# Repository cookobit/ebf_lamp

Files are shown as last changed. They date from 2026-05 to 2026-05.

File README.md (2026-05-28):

# EBF Lamp Project

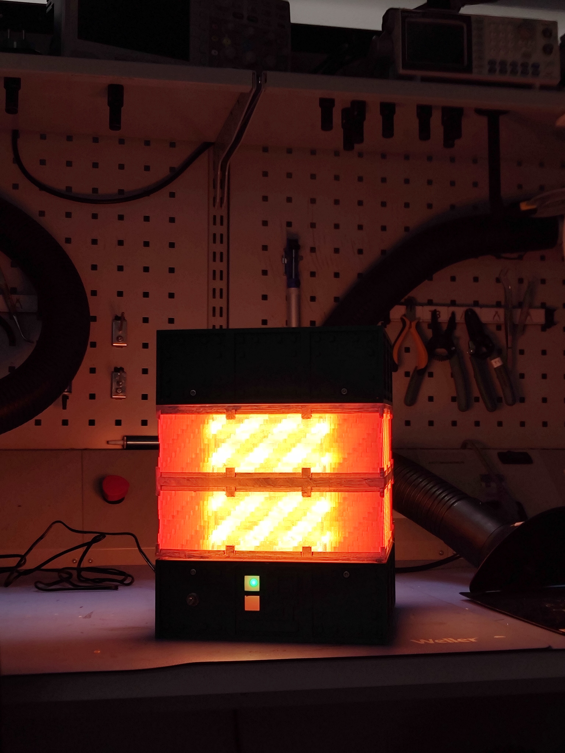
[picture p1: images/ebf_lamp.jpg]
EBF Lamp assembled


You came after the Electrical Blast Furnace (EBF) from GregTech modpacks, especially GTNH. 
This repository contains all production files to date, plus special 3D-print files you can print at home and assemble yourself.

## HOW TO PRINT THE EBF

1. Download the whole repository.
2. In the '3D_prints' folder, find files for 3D printing.
3. The STLs come in two options: the **lamp version**, or for the r**egular version** (empty inside), which is simpler.
4. The lamp version requires a custom PCB, a step-down voltage module, and a power inlet. Because of these custom components, a full reproduction of the lamp from this repo is not possible in its current state.

IMPORTANT: Current dimensions are 192x192x256 mm for the lamp, change the scale for regular version, since the lamp has mounting holes for M3 screws and other components.

## What's in this repository?
In short, the STLs I made so far, as well as some of the design files and software for ESP32 XIAO module. They are separated in two dedicated folders: firmware and hardware.
The firmware was used in the Arduino IDE for flashing the program there, and the hardware was designed in the KiCad, dedicated open-source PCB design software. 

## Plans for the future:

The repo won't have a complete support and maintained actively, because of the real life stuff.
* New PCB for electronics integration. It should integrate the power inlet and complete sensor and hardware integration.
* An optional buzzer for the EBF to make the "working" sounds.
* A humidifier on top, active while the EBF is "running".

## License
Hardware files are licensed under **CERN-OHL-P**; software is licensed under the **MIT License**. See the respective directories for full license text.

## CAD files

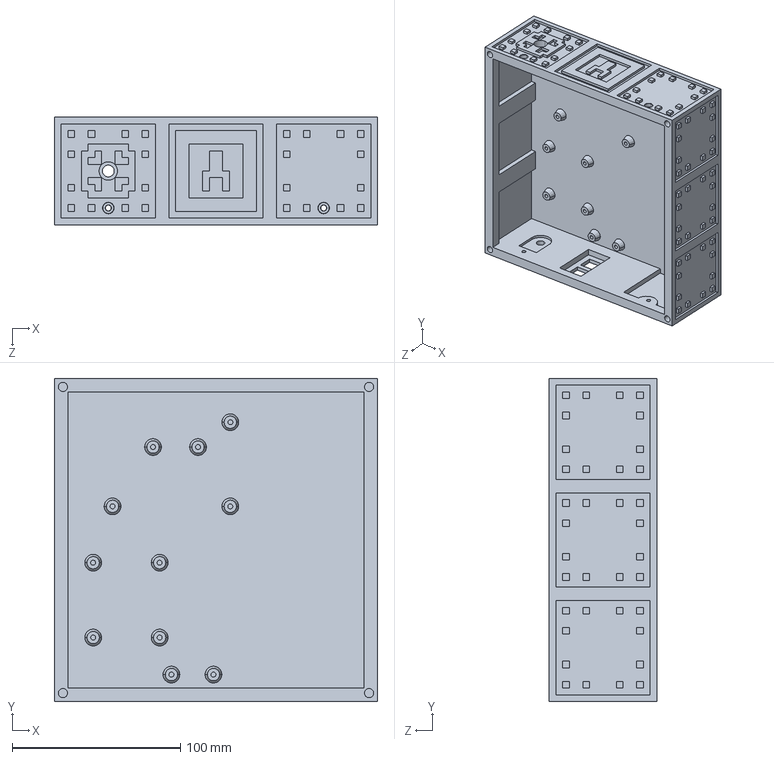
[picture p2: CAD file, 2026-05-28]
3D_prints/lamp_version/EBF_bottom.STEP
192.0 x 192.0 x 64.0 mm

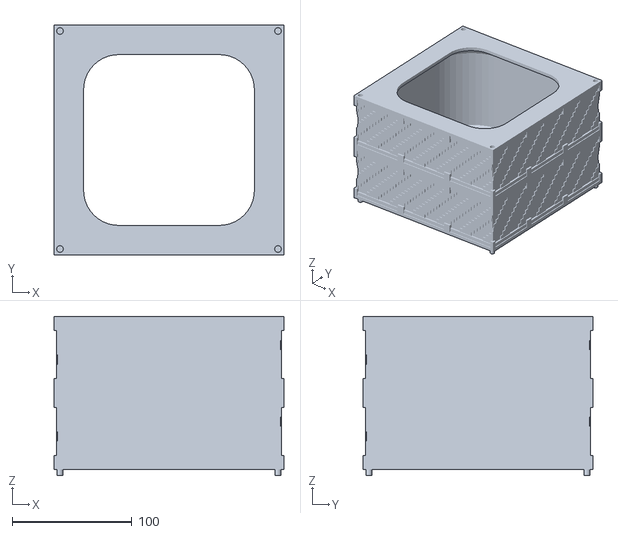
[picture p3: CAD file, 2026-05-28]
3D_prints/regular_version/EBF_coils_regular.STL
192.0 x 192.0 x 133.0

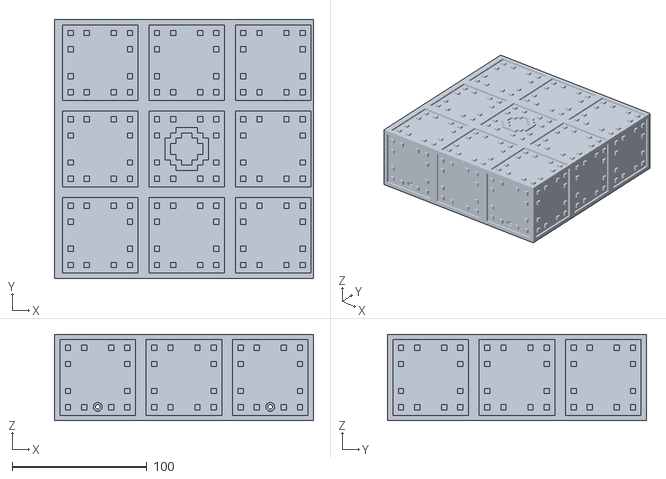
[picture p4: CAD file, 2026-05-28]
3D_prints/lamp_version/EBF_top.STL
192.0 x 192.0 x 64.0

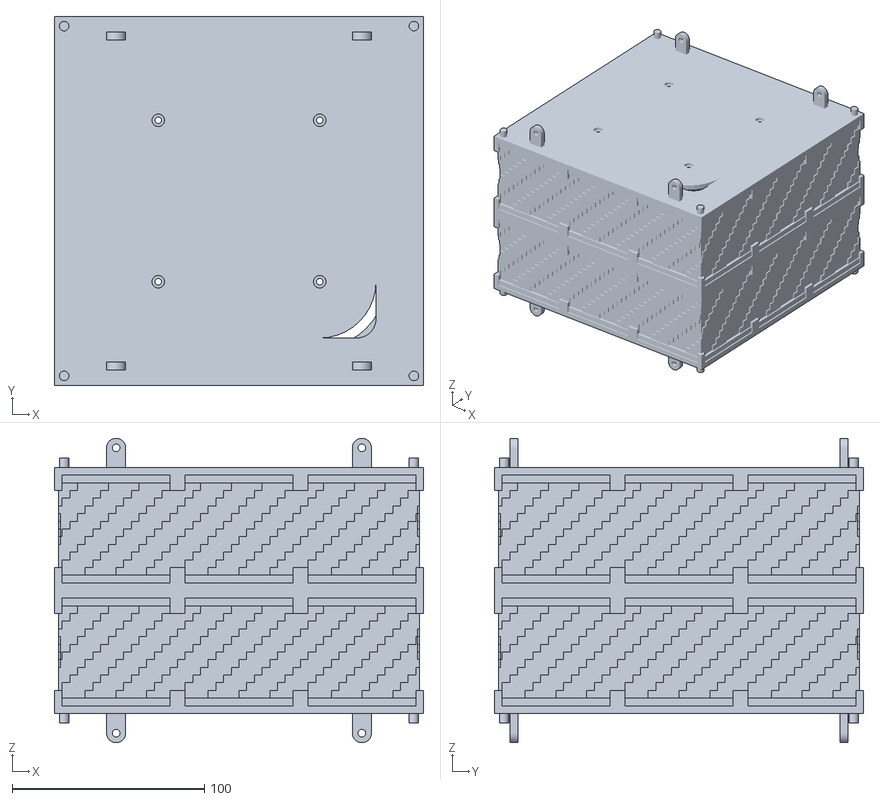
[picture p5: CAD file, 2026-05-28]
3D_prints/lamp_version/EBF_coils.STL
192.0 x 192.0 x 158.4

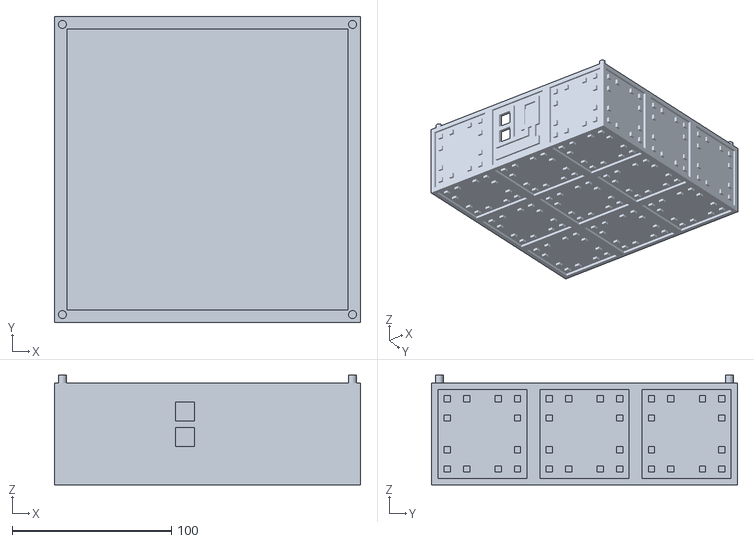
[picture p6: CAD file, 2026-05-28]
3D_prints/regular_version/EBF_bottom_regular.STL
192.0 x 192.0 x 69.0

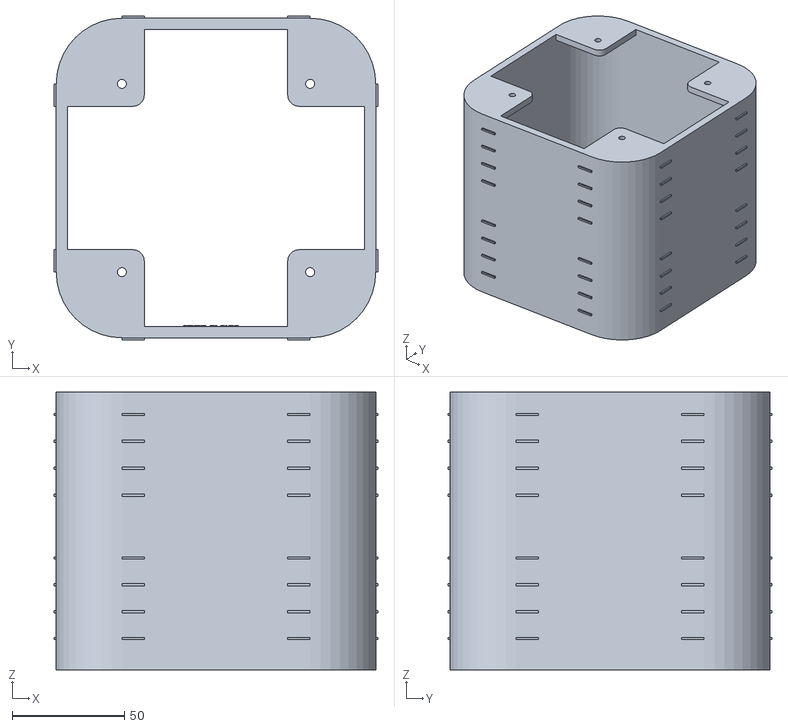
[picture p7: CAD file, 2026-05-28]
3D_prints/lamp_version/LED_holder.STL
144.6 x 144.6 x 124.0

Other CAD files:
3D_prints/regular_version/EBF_top_regular.STL

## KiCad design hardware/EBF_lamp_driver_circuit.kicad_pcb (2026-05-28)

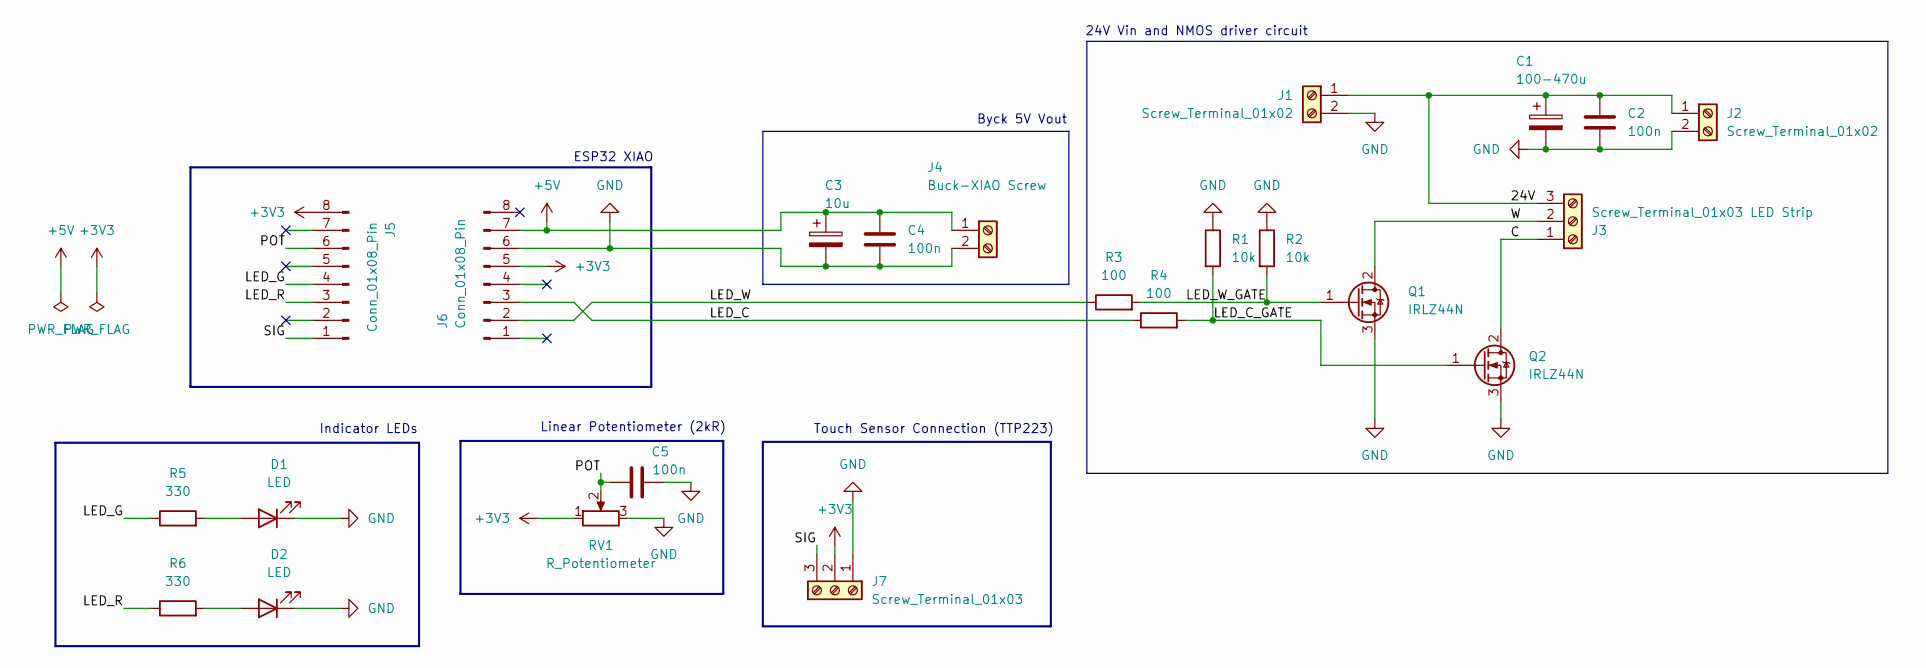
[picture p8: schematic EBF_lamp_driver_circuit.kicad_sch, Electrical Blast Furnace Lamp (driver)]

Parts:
C1: 100-470u; CP_Radial_D6.3mm_P2.50mm
C2, C4, C5: 100n; C_Disc_D3.0mm_W2.0mm_P2.50mm
C3: 10u; CP_Radial_D6.3mm_P2.50mm
D1, D2: LED; LED_D5.0mm
J1, J2: Screw_Terminal_01x02; TerminalBlock_RND_205-00045_1x02_P5.00mm_Horizontal
J3: Screw_Terminal_01x03 LED Strip; TerminalBlock_RND_205-00046_1x03_P5.00mm_Horizontal
J4: Buck-XIAO Screw; TerminalBlock_RND_205-00045_1x02_P5.00mm_Horizontal
J5, J6: Conn_01x08_Pin; PinSocket_1x08_P2.54mm_Vertical
J7: Screw_Terminal_01x03; TerminalBlock_RND_205-00046_1x03_P5.00mm_Horizontal
Q1, Q2: IRLZ44N; TO-220-3_Horizontal_TabDown
R1, R2: 10k; R_Axial_DIN0207_L6.3mm_D2.5mm_P10.16mm_Horizontal
R3, R4: 100; R_Axial_DIN0207_L6.3mm_D2.5mm_P10.16mm_Horizontal
R5, R6: 330; R_Axial_DIN0207_L6.3mm_D2.5mm_P10.16mm_Horizontal
RV1: R_Potentiometer; PinHeader_1x03_P2.54mm_Vertical

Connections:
+3V3: J5.8, J6.5, J7.2, RV1.1
+5V: C3.1, C4.1, J4.1, J6.7
/24V: C1.1, C2.1, J1.1, J2.1, J3.3
/C: J3.1, Q2.2 (D)
/LED_C: J6.3, R4.1
/LED_C_GATE: Q2.1 (G), R1.2, R4.2
/LED_G: J5.4, R5.1
/LED_R: J5.3, R6.1
/LED_W: J6.2, R3.1
/LED_W_GATE: Q1.1 (G), R2.2, R3.2
/POT: C5.1, J5.6, RV1.2
/SIG: J5.1, J7.3
/W: J3.2, Q1.2 (D)
GND: C1.2, C2.2, C3.2, C4.2, C5.2, D1.1 (K), D2.1 (K), J1.2, J2.2, J4.2, J6.6, J7.1, Q1.3 (S), Q2.3 (S), R1.1, R2.1, RV1.3
unnamed: D1.2 (A), R5.2
unnamed: D2.2 (A), R6.2

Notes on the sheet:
Touch Sensor Connection (TTP223)
Indicator LEDs
Linear Potentiometer (2kR)
Byck 5V Vout
ESP32 XIAO
24V Vin and NMOS driver circuit

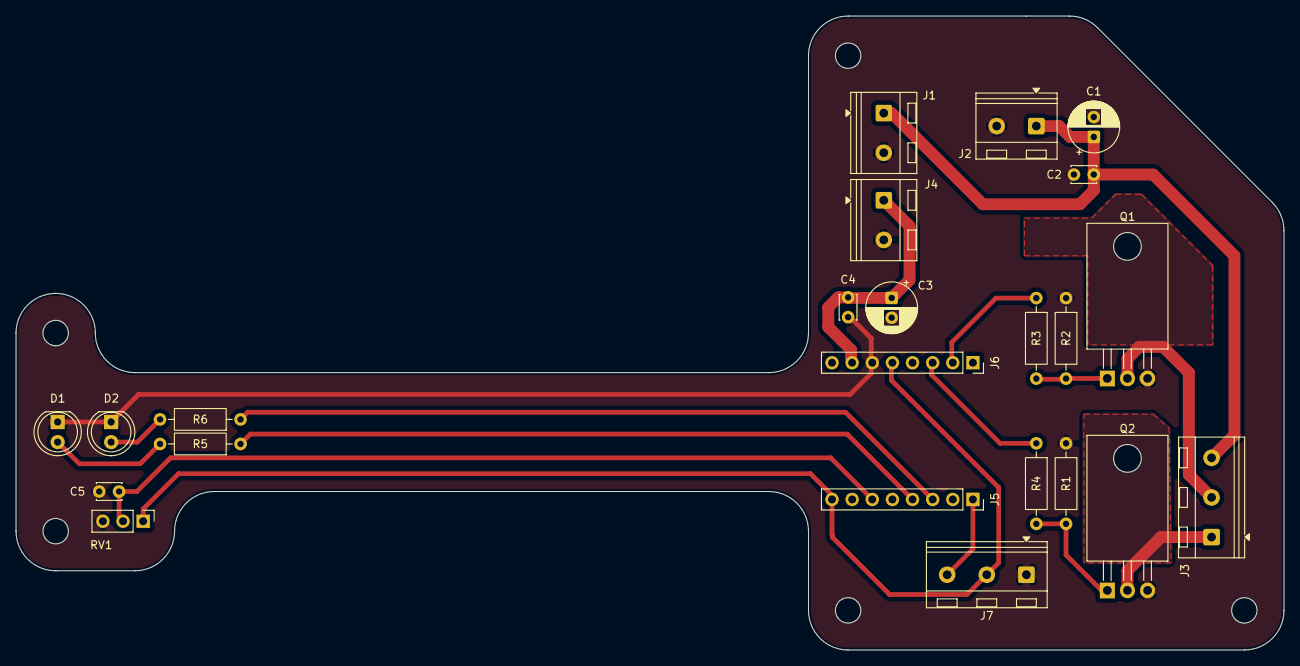
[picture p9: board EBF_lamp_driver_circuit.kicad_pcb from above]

Board: 2 copper layers, 160.0 x 80.0 mm, 23 parts (0 on the bottom side), 16 nets.

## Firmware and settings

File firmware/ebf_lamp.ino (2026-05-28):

// SPDX-License-Identifier: MIT
// Copyright (c) 2026 Kirill Levo (cookobit)
// EBF Lamp Firmware
// XIAO ESP32-S3
// Normal mode: CCT lamp with 3 profiles + pot-controlled warm/cold mix.
// Furnace mode: 5 rapid taps fires up the EBF — slow ramp to peak,
//               subtle breathe at operating temperature, 5 more taps cools down.
//               A third 5-tap during cooldown snaps fully off.

// ── Debug ─────────────────────────────────────────────────────
#define DEBUG true

// ── Pins ─────────────────────────────────────────────────────
#define PIN_POT       2
#define PIN_LED_GREEN 5
#define PIN_LED_RED   4
#define PIN_PWM_WARM  7
#define PIN_PWM_COLD  8
#define PIN_TOUCH     43

// ── PWM ──────────────────────────────────────────────────────
#define PWM_FREQ      1000
#define PWM_RES       8

// ── Profiles (gamma-corrected for perceptual linearity) ──────
const uint8_t PROFILES[3] = {
  255,   // Profile 1: 100% perceived
   127,   // Profile 2:  50% perceived
   25    // Profile 3:  25% perceived
};

// ── Timing ───────────────────────────────────────────────────
#define PROFILE_WINDOW_MS    2000
#define DEBOUNCE_MS          50

// ── Furnace mode ─────────────────────────────────────────────
#define TURBO_TAP_COUNT          5
#define TURBO_TAP_WINDOW_MS      1500
#define HEAT_UP_MS               15000   // 15 s heat-up ramp
#define COOL_DOWN_MS             3000    //  3 s snappy cool-down
#define BREATHE_PERIOD_MS        4000    // operational breathing cycle
#define OPERATIONAL_TIMEOUT_MS   (10UL * 60UL * 1000UL)  // 10 min auto-cool
#define BREATHE_DEPTH            0.15f   // ±15% pulse around peak
#define FURNACE_PEAK_WARM        255     // Cupronickel orange — saturated
#define FURNACE_PEAK_COLD        128     // adds flux without killing the warmth

// ── State ────────────────────────────────────────────────────
enum FurnaceState {
  STATE_NORMAL,
  STATE_HEATING,
  STATE_OPERATIONAL,
  STATE_COOLING
};

bool          lampOn          = false;
uint8_t       profileIndex    = 0;
bool          lastTouchState  = false;
unsigned long offTime         = 0;
unsigned long lastDebounce    = 0;

FurnaceState  furnaceState    = STATE_NORMAL;
unsigned long stateStartTime  = 0;
uint8_t       savedProfile    = 0;
bool          savedLampOn     = false;

unsigned long tapTimes[TURBO_TAP_COUNT] = {0};
uint8_t       tapHead = 0;

// ── Helpers ──────────────────────────────────────────────────

void getPWMValues(uint8_t &warmDuty, uint8_t &coldDuty) {
  int adcVal = analogRead(PIN_POT);
  float t = adcVal / 4095.0f;
  uint8_t profile = PROFILES[profileIndex];
  warmDuty = (uint8_t)((1.0f - t) * profile);
  coldDuty = (uint8_t)(t * profile);
}

void recordTap(unsigned long now) {
  tapTimes[tapHead] = now;
  tapHead = (tapHead + 1) % TURBO_TAP_COUNT;
}

bool isTurboSequence(unsigned long now) {
  unsigned long oldest = tapTimes[tapHead];
  if (oldest == 0) return false;
  return (now - oldest) <= TURBO_TAP_WINDOW_MS;
}

void clearTapHistory() {
  for (uint8_t i = 0; i < TURBO_TAP_COUNT; i++) tapTimes[i] = 0;
  tapHead = 0;
}

void applyLampNormal() {
  if (!lampOn) {
    ledcWrite(PIN_PWM_WARM, 0);
    ledcWrite(PIN_PWM_COLD, 0);
    digitalWrite(PIN_LED_GREEN, LOW);
    digitalWrite(PIN_LED_RED,   HIGH);
  } else {
    uint8_t w, c;
    getPWMValues(w, c);
    ledcWrite(PIN_PWM_WARM, w);
    ledcWrite(PIN_PWM_COLD, c);
    digitalWrite(PIN_LED_GREEN, HIGH);
    digitalWrite(PIN_LED_RED,   LOW);
  }
}

// Apply furnace state, called every loop iteration when active
void applyFurnaceState() {
  unsigned long now     = millis();
  unsigned long elapsed = now - stateStartTime;
  float totalNorm = 0.0f;

  switch (furnaceState) {
    case STATE_HEATING: {
      float progress = (float)elapsed / HEAT_UP_MS;
      if (progress >= 1.0f) {
        furnaceState   = STATE_OPERATIONAL;
        stateStartTime = now;
        if (DEBUG) Serial.println("→ Furnace at operating temperature");
        progress = 1.0f;
      }
      // Smoothstep S-curve: anticipation -> ramp -> tapering
      totalNorm = progress * progress * (3.0f - 2.0f * progress);
      break;
    }

    case STATE_OPERATIONAL: {
      // Slow breathing around peak, active EBF processing
      float phase = (float)(elapsed % BREATHE_PERIOD_MS) / BREATHE_PERIOD_MS;
      phase *= 2.0f * PI;
      totalNorm = 1.0f - (BREATHE_DEPTH * 0.5f * (1.0f - cos(phase)));

      // Auto-cool after timeout
      if (elapsed >= OPERATIONAL_TIMEOUT_MS) {
        furnaceState   = STATE_COOLING;
        stateStartTime = now;
        if (DEBUG) Serial.println("→ Furnace cooling (auto-timeout)");
      }
      break;
    }

    case STATE_COOLING: {
      float progress = (float)elapsed / COOL_DOWN_MS;
      if (progress >= 1.0f) {
        // Return to where the user was before firing up
        furnaceState = STATE_NORMAL;
        profileIndex = savedProfile;
        lampOn       = savedLampOn;
        clearTapHistory();
        applyLampNormal();
        if (DEBUG) Serial.println("→ Furnace cold");
        return;
      }
      float remaining = 1.0f - progress;
      totalNorm = remaining * remaining;
      break;
    }

    default:
      return;
  }

  // Drive each channel against its own peak, scaled by totalNorm
  uint8_t warmDuty = (uint8_t)(totalNorm * FURNACE_PEAK_WARM);
  uint8_t coldDuty = (uint8_t)(totalNorm * FURNACE_PEAK_COLD);

  ledcWrite(PIN_PWM_WARM, warmDuty);
  ledcWrite(PIN_PWM_COLD, coldDuty);
  digitalWrite(PIN_LED_GREEN, HIGH);
  digitalWrite(PIN_LED_RED,   HIGH);   // both indicators ON = furnace mode
}

void enterHeating() {
  savedProfile   = profileIndex;
  savedLampOn    = lampOn;
  furnaceState   = STATE_HEATING;
  stateStartTime = millis();
  clearTapHistory();
  if (DEBUG) Serial.println("→ EBF firing up");
}

void enterCooling() {
  furnaceState   = STATE_COOLING;
  stateStartTime = millis();
  clearTapHistory();
  if (DEBUG) Serial.println("→ EBF cooling down");
}

void handleTouch() {
  unsigned long now = millis();
  recordTap(now);

  if (isTurboSequence(now)) {
    switch (furnaceState) {
      case STATE_NORMAL:
        enterHeating();
        break;
      case STATE_HEATING:
      case STATE_OPERATIONAL:
        enterCooling();
        break;
      case STATE_COOLING:
        // Second 5-tap during cooldown → snap to fully off
        furnaceState = STATE_NORMAL;
        profileIndex = savedProfile;
        lampOn       = savedLampOn;
        clearTapHistory();
        applyLampNormal();
        if (DEBUG) Serial.println("→ Cooldown skipped, fully off");
        break;
    }
    return;
  }

  // Swallow individual taps while in furnace mode
  if (furnaceState != STATE_NORMAL) return;

  // Normal lamp logic
  if (lampOn) {
    lampOn = false;
    offTime = now;
    applyLampNormal();
    if (DEBUG) Serial.println("→ Lamp OFF");
  } else {
    if ((now - offTime) <= PROFILE_WINDOW_MS) {
      profileIndex = (profileIndex + 1) % 3;
      if (DEBUG) Serial.println("→ Profile advanced");
    } else {
      profileIndex = 0;
      if (DEBUG) Serial.println("→ Profile reset");
    }
    lampOn = true;
    applyLampNormal();
    if (DEBUG) {
      Serial.print("→ Lamp ON, Profile ");
      Serial.print(profileIndex + 1);
      Serial.print(" (");
      Serial.print((PROFILES[profileIndex] * 100) / 255);
      Serial.println("%)");
    }
  }
}

// ── Setup ────────────────────────────────────────────────────
void setup() {
  pinMode(PIN_LED_GREEN, OUTPUT);
  pinMode(PIN_LED_RED,   OUTPUT);
  pinMode(PIN_TOUCH, INPUT);
  analogReadResolution(12);
  ledcAttach(PIN_PWM_WARM, PWM_FREQ, PWM_RES);
  ledcAttach(PIN_PWM_COLD, PWM_FREQ, PWM_RES);
  applyLampNormal();

  if (DEBUG) {
    Serial.begin(115200);
    Serial.println("EBF Lamp — DEBUG mode");
    Serial.println("State | Profile | ADC  | Warm | Cold");
    Serial.println("------+---------+------+------+-----");
  }
}

// ── Main loop ────────────────────────────────────────────────
void loop() {
  bool touchNow = digitalRead(PIN_TOUCH);
  unsigned long now = millis();

  if (touchNow && !lastTouchState && (now - lastDebounce) > DEBOUNCE_MS) {
    lastDebounce = now;
    handleTouch();
  }
  lastTouchState = touchNow;

  // Drive outputs
  if (furnaceState != STATE_NORMAL) {
    applyFurnaceState();
  } else if (lampOn) {
    uint8_t w, c;
    getPWMValues(w, c);
    ledcWrite(PIN_PWM_WARM, w);
    ledcWrite(PIN_PWM_COLD, c);
  }

  // Debug print
  if (DEBUG) {
    static unsigned long lastPrint = 0;
    if (millis() - lastPrint >= 250) {
      lastPrint = millis();
      int adcVal = analogRead(PIN_POT);
      uint8_t w, c;
      getPWMValues(w, c);

      const char* stateStr;
      switch (furnaceState) {
        case STATE_HEATING:     stateStr = "HEAT"; break;
        case STATE_OPERATIONAL: stateStr = "OPER"; break;
        case STATE_COOLING:     stateStr = "COOL"; break;
        default:                stateStr = lampOn ? "ON  " : "OFF "; break;
      }
      Serial.print(stateStr);
      Serial.print("  | P");
      Serial.print(profileIndex + 1);
      Serial.print("      | ");
      Serial.print(adcVal);
      Serial.print(" | ");
      Serial.print(w);
      Serial.print("   | ");
      Serial.println(c);
    }
  }

  delay(10);
}

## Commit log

2026-05-28 STL files
    [EBF_bottom.STEP, EBF_bottom_regular.STL, EBF_coils.STL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]
2026-05-28 Layout change
    [EBF_bottom.STEP, EBF_bottom_regular.STL, EBF_coils.STL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]
2026-05-28 Design Files
    [EBF_lamp_driver_circuit.kicad_pcb, EBF_lamp_driver_circuit.kicad_sch]
